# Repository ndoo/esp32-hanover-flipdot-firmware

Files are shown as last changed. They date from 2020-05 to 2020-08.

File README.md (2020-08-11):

# ESP32 Hanover Flip-dot Sign Controller

## PCB

Reference PCB is available at [ndoo/esp32-hanover-flipdot](https://github.com/ndoo/esp32-hanover-flipdot)

## Demo Video

[ESP32 Hanover Flip-dot Sign Controller - Demos](https://youtu.be/oSv1yEUelBg)

## Firmware

### IDE Prerequisites

You will need a working [VS Code](https://code.visualstudio.com/) and [PlatformIO](https://platformio.org/) development environment, with ESP32 support installed.

Libraries should automatically download as they have been specified in `platformio.ini`.

### First Use

#### Powering the Board

A freshly assembled board will not have any sketch running on it, and will be in bootloader bode waiting for firmware upload over serial. You will need a TTL USB-serial adapter, and one of the following methods of powering the board:

* Connect Tx, Rx, VCC and GND to USB-serial adapter - **USB-serial adapter must be set to 3.3V VCC or the ESP32 SIP will be irreversibly damaged**
* Connect Tx, Rx and GND to USB-serial adapter, then connect 18VDC power supply - **ground PCB to USB-serial adapter before connecting DC supply to avoid ESD**

**Do not connect RS-232 level signalling to the board, the ESP32 SIP will be damaged by signalling above TTL levels.**

#### Compiling and Uploading Sketch

The default `platformio.ini` provided here is configured to OTA upload for your convenience, however that means you need to edit this file for the initial flash, in order to program over USB-serial, as the board is not running firmware capable of OTA updates.

Comment these 2 lines out by preceding them with a semicolon (`;`):

```
upload_protocol = espota
upload_port = Hanover-Flipdot.local
```

Then, test the build by clicking the tick in the lower left status bar of VS Code + PlatformIO.

If the build succeeds, click the rightwards-pointing arrow in the lower left status bar of VS Code + PlatformIO. This will link the firmware and attempt to upload it to the board's ESP32 over USB-serial.

#### Configuring Wi-Fi

You should see a new wireless AP with the SSID `ESP_<YOUR_ESP_UNIQUE_MAC>`. Connect to it and you should be automatically redirected to a portal that allows you to connect the ESP32 to your Wi-Fi.

If the connection is successful, you should be able to send data to the board using the Python scripts found in the `demos` folder. If the connection fails, the ESP32 will automatically time out and re-start the temporary wireless AP for you to continue Wi-Fi setup.

Don't forget to uncomment the previously commented-out lines in `platformio.ini` to re-enable OTA uploads.

#### Rescue Programming

If you need to re-upload a sketch over serial, take note that this board does not have automatic boot and reset circuitry, so you will need to press the two buttons on the board in the following sequence to enter download mode, before uploading a sketch:

1. Hold down RST button
2. Hold down PGM button
3. Release RST button
4. Release PGM button

This may take a few tries to get the timing right, as the buttons are tiny and placed close together.

#### Troubleshooting

* Board not receiving UDP packets
  * The board, by default, listends on multicast IP 239.1.2.3 on UDP port 8080 (port can be changed in `include/main.h`)
  * Your LAN routers, switches or Wi-Fi access points may be configured to drop multicast packets, or may need IGMP snooping to be enabled
* OTA not working on Windows due to Hanover-Flipdot.local not resolving
  * You may need to install an mDNS resolver software such as [Apple's Bonjour Print Services for Windows](https://support.apple.com/kb/DL999)

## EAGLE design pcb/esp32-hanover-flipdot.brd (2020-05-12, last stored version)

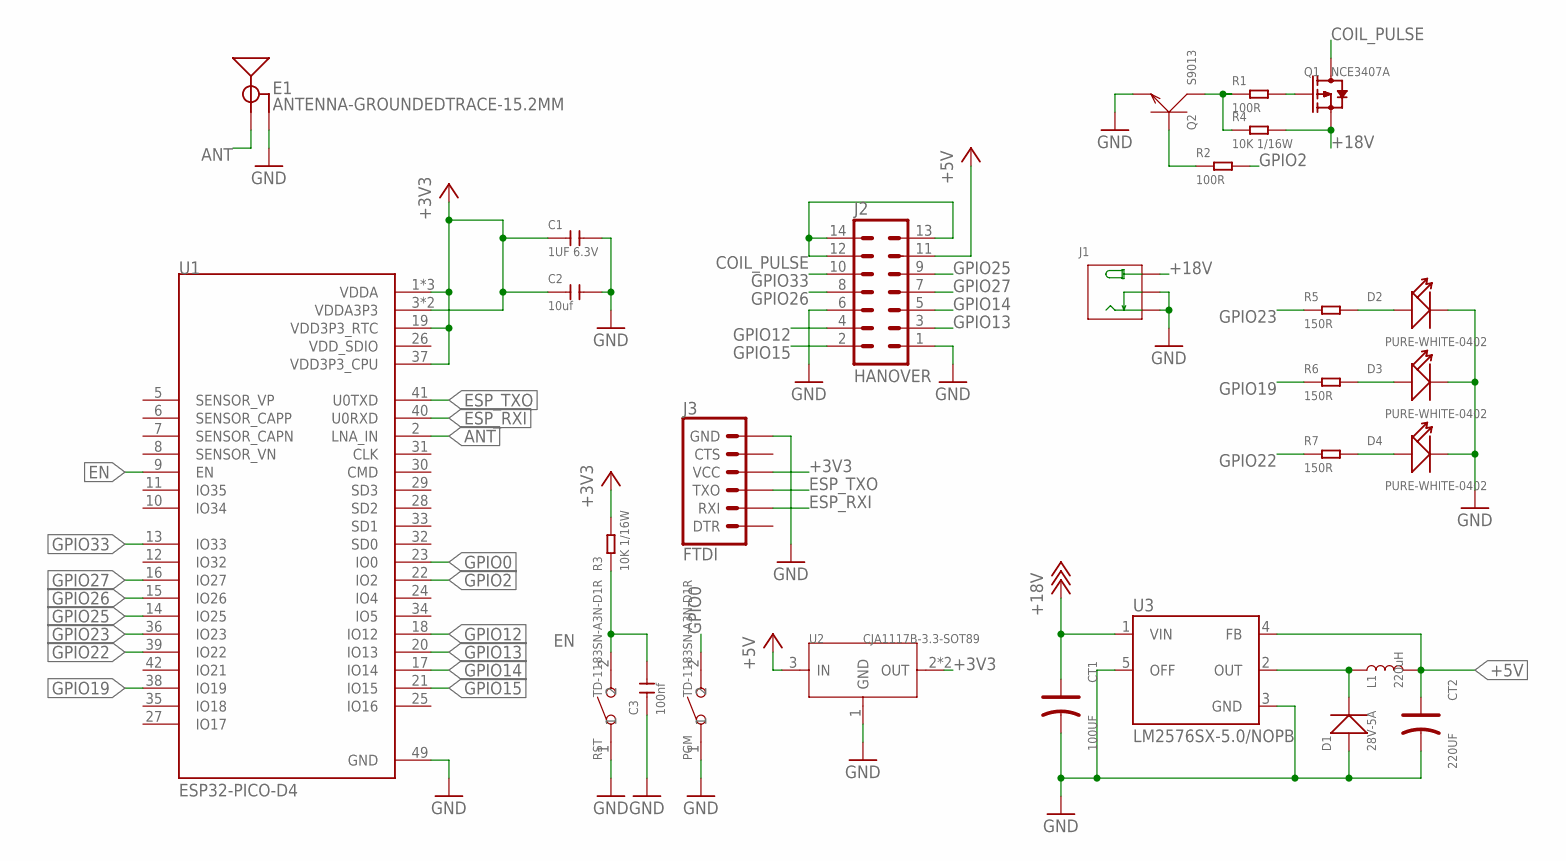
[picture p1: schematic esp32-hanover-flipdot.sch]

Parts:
C1: 1UF 6.3V; C0402
C2: 10uf; C0402
C3: 100nf; C0402
CT1: 100UF; ELECTRO-SMD-C-6MM; MPN 302030000
CT2: 220UF; ELECTRO-SMD-C-6MM
D1: 28V-5A; DO-214AA
D2, D3, D4: PURE-WHITE-0402; LED-0402
E1: ANTENNA-GROUNDEDTRACE-15.2MM; TRACE_ANTENNA_2.4GHZ_15.2MM
J1: DC-005; 3P-L14.2*W11.0*H9.0MM
J2: HANOVER; ML14
J3: FTDI; 6_PIN_SERIAL_TARGET_SIDE_W_SILK
L1: 220uH; CR54
PGM: TD-1183SN-A3N-D1R; SW2-2.6-3.0X2.5X1.2+0.4MM
Q1: NCE3407A; SOT-23
Q2: S9013; SOT-23
R1, R2: 100R; R0402
R3, R4: 10K 1/16W; R0402
R5, R6, R7: 150R; R0402; MPN RC0402FR-07150RL
RST: TD-1183SN-A3N-D1R; SW2-2.6-3.0X2.5X1.2+0.4MM
U1: ESP32-PICO-D4; PQFN50P700X700X104-49N
U2: CJA1117B-3.3-SOT89; SOT-89
U3: LM2576SX-5.0/NOPB; TO263-5

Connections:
+3V3: C1.1, C2.1, J3.P$4 (VCC), R3.2, U1.1 (VDDA), U1.3 (VDDA3P3), U1.4 (VDDA3P3), U1.19 (VDD3P3_RTC), U1.37 (VDD3P3_CPU), U1.43 (VDDA), U1.46 (VDDA), U2.2 (OUT), U2.4 (OUT)
+5V: CT2.+, J2.11, L1.P$2 (2), U2.3 (IN), U3.4 (FB)
+18V: CT1.+, J1.+B (+), J1.+T (+), Q1.2 (S), R4.2, U3.1 (VIN)
ANT: E1.ANT (SIGNAL), U1.2 (LNA_IN)
COIL_PULSE: J2.12, J2.13, J2.14, Q1.3 (D)
EN: C3.2, R3.1, RST.2, U1.9 (EN)
ESP_RXI: J3.P$3 (RXI), U1.40 (U0RXD)
ESP_TXO: J3.P$2 (TXO), U1.41 (U0TXD)
GND: C1.2, C2.2, C3.1, CT1.-, CT2.-, D1.+, D2.-, D3.-, D4.-, E1.GND, J1.-1B (-), J1.-1T (-), J1.-2B (CDN), J1.-2T (CDN), J2.1, J2.6, J3.P$6 (GND), PGM.1, Q2.2 (E), RST.1, U1.49 (GND), U2.1 (GND), U3.3 (GND), U3.5 (OFF)
GPIO0: PGM.2, U1.23 (IO0)
GPIO2: R2.2, U1.22 (IO2)
GPIO12: J2.4, U1.18 (IO12)
GPIO13: J2.3, U1.20 (IO13)
GPIO14: J2.5, U1.17 (IO14)
GPIO15: J2.2, U1.21 (IO15)
GPIO19: R6.1, U1.38 (IO19)
GPIO22: R7.1, U1.39 (IO22)
GPIO23: R5.1, U1.36 (IO23)
GPIO25: J2.9, U1.14 (IO25)
GPIO26: J2.8, U1.15 (IO26)
GPIO27: J2.7, U1.16 (IO27)
GPIO33: J2.10, U1.13 (IO33)
unnamed: Q1.1 (G), R1.2
unnamed: Q2.3 (C), R1.1, R4.1
unnamed: Q2.1 (B), R2.1
unnamed: D1.-, L1.P$1 (1), U3.2 (OUT)
unnamed: D2.+, R5.2
unnamed: D3.+, R6.2
unnamed: D4.+, R7.2
VDD_SDIO: U1.26 (VDD_SDIO)

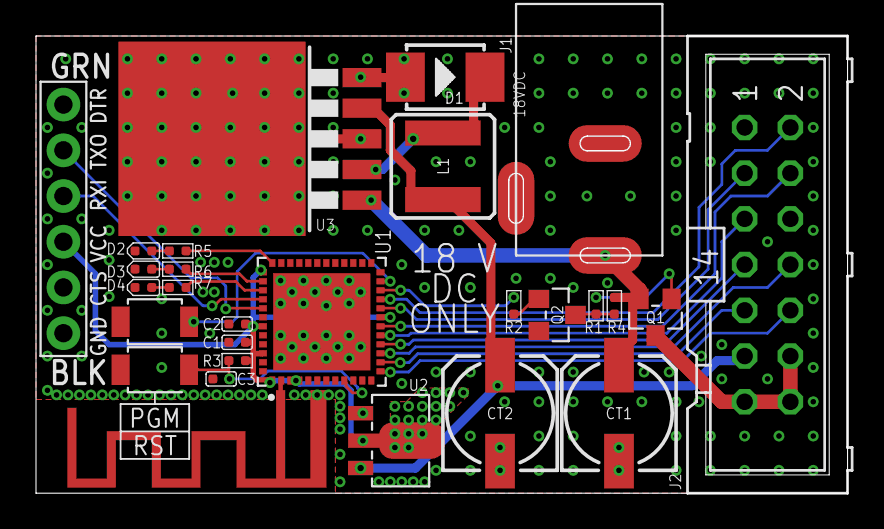
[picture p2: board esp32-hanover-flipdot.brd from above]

Board: 2 copper layers, 45.1 x 25.4 mm, 28 parts (0 on the bottom side), 29 nets.

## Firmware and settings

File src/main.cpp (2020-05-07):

#include <main.h>

#include <Arduino.h>
#include <WiFi.h>
#include <WiFiManager.h>
#include <ESPmDNS.h>
#include <WiFiUdp.h>
#include <ArduinoOTA.h>

extern "C"
{
#include "freertos/FreeRTOS.h"
}

#include <Hanover_Flipdot.h>
#include <Adafruit_GFX.h>
#include <Fonts/TomThumb.h>

#include "AsyncUDP.h"

Hanover_Flipdot flipdot = Hanover_Flipdot();
AsyncUDP udp;
IPAddress multicastGroup = IPAddress(239, 1, 2, 3);

bool panelOverride = false;

void debugText(String text, uint8_t seconds = 0)
{
    if (seconds)
        flipdot.backup();
    flipdot.clear();
    flipdot.setCursor(0, 5);
    flipdot.print(text);
    flipdot.writeDisplay();
    if (seconds)
    {
        sleep(seconds);
        flipdot.restore();
        flipdot.writeDisplay();
    }
}

void configModeCallback(WiFiManager *myWiFiManager)
{
    debugText("Setup: " + myWiFiManager->getConfigPortalSSID());
}

void onUdpPacket(AsyncUDPPacket packet)
{
    if (panelOverride)
        return;

    uint16_t len = (uint16_t)flipdot.getWidth() * flipdot.getHeight() / 8;
    if (packet.length() != len)
        return;

    memcpy(flipdot.db_buffer, packet.data(), len);
    flipdot.writeDisplay();
}

void connectToUdp()
{
    if (udp.listenMulticast(multicastGroup, UDP_PORT))
    {
        // Power optimizations
        setCpuFrequencyMhz(80);

        // Uncomment for better receive performance, e.g. for videos
        // ESP32 may get hot!
        WiFi.setSleep(false);

        // UDP handler function
        udp.onPacket(onUdpPacket);
    }
}

void WiFiEvent(WiFiEvent_t event)
{
    Serial.printf("[WiFi-event] event: %d\n", event);
    String ip_msg = "IP: ";
    ip_msg += multicastGroup.toString() + "\nPort: " + UDP_PORT;
    switch (event)
    {
    case SYSTEM_EVENT_STA_START:
        debugText("Wi-Fi connecting", 3);
        break;
    case SYSTEM_EVENT_STA_GOT_IP:
        connectToUdp();
        debugText(ip_msg);
        break;
    case SYSTEM_EVENT_STA_DISCONNECTED:
        debugText("Wi-Fi lost", 3);
        break;
    case SYSTEM_EVENT_STA_LOST_IP:
        debugText("Wi-Fi lost IP", 3);
        break;
    }
}
void setup()
{

    Serial.begin(115200);

    flipdot.begin();
    flipdot.setFont(&TomThumb);
    flipdot.setTextSize(1);

    WiFi.onEvent(WiFiEvent);

    WiFiManager wifiManager;
    wifiManager.setAPCallback(configModeCallback);
    wifiManager.setHostname("Hanover-Flipdot");
    wifiManager.autoConnect();

    ArduinoOTA.onStart([]() {
                  // Stash flipdot contents and lock display to prevent slowdown of OTA by synchronous display updates from UDP
                  flipdot.backup();
                  panelOverride = true;
                  String type;
                  if (ArduinoOTA.getCommand() == U_FLASH)
                  {
                      type = "FW";
                  }
                  else
                  { // U_FS
                      type = "FS";
                  }
                  debugText("OTA " + type);
              })
        .onProgress([](unsigned int progress, unsigned int total) {
            String ota_msg = "OTA ";
            ota_msg += String(progress / (total / 100)) + "%";
            debugText(ota_msg);
        })
        .onEnd([]() {
            debugText("OTA success!");
        })
        .onError([](ota_error_t error) {
            String ota_msg = "OTA error " + String(error) + ":\n";
            switch (error)
            {
            case OTA_AUTH_ERROR:
                ota_msg += "Auth Failed";
                break;
            case OTA_BEGIN_ERROR:
                ota_msg += "Begin Failed";
                break;
            case OTA_CONNECT_ERROR:
                ota_msg += "Connect Failed";
                break;
            case OTA_RECEIVE_ERROR:
                ota_msg += "Receive Failed";
                break;
            case OTA_END_ERROR:
                ota_msg += "End Failed";
                break;
            }
            debugText(ota_msg);
            sleep(3);
            panelOverride = false;
            flipdot.restore();
            flipdot.writeDisplay();
        });

    ArduinoOTA.begin();
}

void loop()
{
    ArduinoOTA.handle();
}

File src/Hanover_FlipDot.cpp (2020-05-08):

#include <Hanover_Flipdot.h>
#include <Arduino.h>
#include <Adafruit_GFX.h>
#include <SPI.h>
#include <Wire.h>
#include <rom/rtc.h>

static const uint8_t pin_enable[] = {PIN_ENABLE1, PIN_ENABLE2, PIN_ENABLE3, PIN_ENABLE4};

Hanover_Flipdot::Hanover_Flipdot(void) : Adafruit_GFX(DB_COLS * DB_BOARDS, DB_ROWS)
{
}

void Hanover_Flipdot::begin(void)
{

    // Set GPIO pins of dot board to output
    pinMode(PIN_ENABLE1, OUTPUT);
    pinMode(PIN_ENABLE2, OUTPUT);
    pinMode(PIN_ENABLE3, OUTPUT);
    pinMode(PIN_ENABLE4, OUTPUT);
    pinMode(PIN_ROW_ADVANCE, OUTPUT);
    pinMode(PIN_COL_ADVANCE_ROW_RESET, OUTPUT);
    pinMode(PIN_COL_RESET, OUTPUT);
    pinMode(PIN_SET_UNSET, OUTPUT);
    pinMode(PIN_COIL_DRIVE, OUTPUT);

    // Set GPIO pins of status LEDs to output
    pinMode(PIN_LED_COIL, OUTPUT);
    pinMode(PIN_LED_ROW, OUTPUT);
    pinMode(PIN_LED_COL, OUTPUT);

    // Set GPIO pins of dot board to low (to avoid potentially overheating coils)
    digitalWrite(PIN_ENABLE1, LOW);
    digitalWrite(PIN_ENABLE2, LOW);
    digitalWrite(PIN_ENABLE3, LOW);
    digitalWrite(PIN_ENABLE4, LOW);
    digitalWrite(PIN_ROW_ADVANCE, LOW);
    digitalWrite(PIN_COL_ADVANCE_ROW_RESET, LOW);
    digitalWrite(PIN_COL_RESET, LOW);
    digitalWrite(PIN_SET_UNSET, LOW);
    digitalWrite(PIN_COIL_DRIVE, LOW);

    if (rtc_get_reset_reason(0) == 1 || rtc_get_reset_reason(0) == 15)
    { // POWERON_RESET || RTCWDT_BROWN_OUT_RESET
        // Lamp test while waiting for power to stabilize (if cold boot)
        digitalWrite(PIN_LED_COIL, HIGH);
        digitalWrite(PIN_LED_ROW, HIGH);
        digitalWrite(PIN_LED_COL, HIGH);
        sleep(1);
    }

    // Set GPIO pins of status LEDs
    digitalWrite(PIN_LED_COIL, LOW);
    digitalWrite(PIN_LED_ROW, LOW);
    digitalWrite(PIN_LED_COL, LOW);

    // Lamp test / force clear
    fillScreen(1);
    writeDisplay();
    clear();
    writeDisplay();
}

uint8_t Hanover_Flipdot::getWidth(void)
{
    return DB_COLS * DB_BOARDS;
}
uint8_t Hanover_Flipdot::getHeight(void)
{
    return DB_ROWS;
}

void Hanover_Flipdot::enable(uint8_t db)
{
    // Unlatch dot board
    digitalWrite(pin_enable[db], HIGH);

    // Clear row and column resets
    digitalWrite(PIN_COL_ADVANCE_ROW_RESET, LOW);
    digitalWrite(PIN_COL_RESET, LOW); // Clear column reset after row, as row reset advances column
}

void Hanover_Flipdot::disable(uint8_t db)
{
    // Hold row and column counters in reset
    digitalWrite(PIN_COL_ADVANCE_ROW_RESET, HIGH);
    digitalWrite(PIN_COL_RESET, HIGH); // Set column reset after row, as row reset advances column

    // Latch dot board
    digitalWrite(pin_enable[db], LOW);
}

void Hanover_Flipdot::advanceRow(void)
{
    digitalWrite(PIN_ROW_ADVANCE, HIGH);
    if (LED_DEBUG)
        digitalWrite(PIN_LED_ROW, HIGH);
    delayMicroseconds(1);
    digitalWrite(PIN_ROW_ADVANCE, LOW);
    if (LED_DEBUG)
        digitalWrite(PIN_LED_ROW, LOW);
    delayMicroseconds(1);
}

void Hanover_Flipdot::advanceCol(void)
{
    digitalWrite(PIN_COL_ADVANCE_ROW_RESET, HIGH);
    if (LED_DEBUG)
        digitalWrite(PIN_LED_COL, HIGH);
    delayMicroseconds(1);
    digitalWrite(PIN_COL_ADVANCE_ROW_RESET, LOW);
    if (LED_DEBUG)
        digitalWrite(PIN_LED_COL, LOW);
    delayMicroseconds(1);
}

void Hanover_Flipdot::flipDot(bool state, uint16_t pulse_time)
{
    digitalWrite(PIN_SET_UNSET, state ^ DB_INVERT ? HIGH : LOW);
    digitalWrite(PIN_COIL_DRIVE, HIGH);
    if (LED_DEBUG)
        digitalWrite(PIN_LED_COIL, HIGH);

    delayMicroseconds(pulse_time);

    digitalWrite(PIN_COIL_DRIVE, LOW);
    if (LED_DEBUG)
        digitalWrite(PIN_LED_COIL, LOW);

    delayMicroseconds(DB_THROTTLE);
}
void Hanover_Flipdot::writeDisplay(void)
{
    // Iterate dot boards
    for (uint8_t db = 0; db < DB_BOARDS; db++)
    {
        bool db_enabled = false;

        uint8_t col_start = db * DB_COLS;
        uint8_t col_end = col_start + DB_COLS;

        // Iterate columns
        uint8_t col_backlog = 0;
        for (uint8_t col = col_start; col < col_end; col++)
        {
            // Iterate rows
            uint8_t row_backlog = 0;
            for (uint8_t row = 0; row < DB_ROWS; row++)
            {
                bool db_buffer_bit = db_buffer[col] & (1 << row);
                bool db_displayed_bit = db_displayed[col] & (1 << row);
                if (db_displayed_bit != db_buffer_bit)
                {
                    // Enable dot-board if first time writing
                    if (!db_enabled)
                    {
                        enable(db);
                        db_enabled = true;
                    }

                    // Increment to match
                    for (uint8_t cb = 0; cb < col_backlog; cb++)
                        advanceCol();
                    for (uint8_t rb = 0; rb < row_backlog; rb++)
                        advanceRow();
                    row_backlog = 0;
                    col_backlog = 0;

                    uint16_t pulse_time = pow(db, 2) * DB_SEQ_THROTTLE_COIL + (db_buffer_bit ? PULSE_COIL_ON : PULSE_COIL_OFF);
                    flipDot(db_buffer_bit, pulse_time);
                }
                row_backlog++;
            } // Iterate rows
            db_displayed[col] = db_buffer[col];
            Serial.println();
            col_backlog++;
        } // Iterate columns
        if (db_enabled)
            disable(db);
    } // Iterate dot boards
}

// Drawing helper functions

void Hanover_Flipdot::clear(void)
{
    for (uint8_t i = 0; i < DB_COLS * DB_BOARDS; i++)
        db_buffer[i] = 0;
}

void Hanover_Flipdot::backup(void)
{
    memcpy(db_backup, db_buffer, sizeof(db_buffer));
}

void Hanover_Flipdot::restore(void)
{
    memcpy(db_buffer, db_backup, sizeof(db_backup));
}

// Drawing functions (Adafruit GFX Primitives)

void Hanover_Flipdot::drawPixel(int16_t x, int16_t y, uint16_t color)
{
    if ((y < 0) || (y >= DB_ROWS))
        return;
    if ((x < 0) || (x >= DB_COLS * DB_BOARDS))
        return;

    if (color)
    {
        db_buffer[x] |= 1 << y;
    }
    else
    {
        db_buffer[x] &= ~(1 << y);
    }
}

void Hanover_Flipdot::fillScreen(uint16_t color)
{
    for (uint8_t i = 0; i < DB_COLS * DB_BOARDS; i++)
        db_buffer[i] = pow(2, DB_ROWS) - 1;
}

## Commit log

2018-11-21 Changed more tName silkscreen text to 11% ratio, fixed R2 silkscreen overlap with CT2 pad, update PCB image.
    [esp32-hanover-flipdot.brd]
2020-05-04 Add PlatformIO project for code that drives the board
    Add PlatformIO project for code that drives the board. Documentation TODO.
2020-05-04 Fix reset routines and transmit data over binary UDP
    [Hanover_FlipDot.cpp, Hanover_Flipdot.h, main.cpp]
2020-05-05 PCB: Disconnect dot board pin 13, 14. Add 18VDC and warning text. Increase space around J2.
    Disconnect dot-board pin 13 and 14 from 18VDC, seems to cause overheating of dot 0,0 on dot boards when boards are not enabled. Works fine without anyway - tested by cutting ribbon cable pins 13, 14.
    Added 18VDC only warning text. Add warning text to disconnect power before connecting or disconnecting dot boards.
    Increase space around J2 as the connector housing is causing stress to neighboring components.
    [esp32-hanover-flipdot.brd, esp32-hanover-flipdot.sch]
2020-05-05 Fix Eagle Seeedstudio DRC
    Routed missing airwires and approved clearance issues
    [esp32-hanover-flipdot.brd]
2020-05-05 Create esp32-hanover-flipdot_2020-05-05-seeed-fusion.zip
    Generate Seeed Fusion PCB Gerbers using Eagle's built in Seeed Fusion 2-layer template
2020-05-05 Update README.md
    Recommend buying 2.54mm through-holes locally to save time/money
2020-05-05 Fix warning silkscreen clipping outside of board dimension
    [esp32-hanover-flipdot.brd]
2020-05-06 More Demos and Updates to Demos
    New demos:
    * clock.py - A simple clock
    * fill.py - Dotboard test - cycles between all on and all off
    * webcam.py - Sends webcam feed to dotboard (written for Windows, trivial to adapt by changing the capture device to 0)
    Improvements/changes
    * imageToBinary.py - invert image as contrast tends to favor white on black on flipdots
    * All demos - change to 96*32 (3* 32*32 dot boards) as that's what I have on hand
2020-05-06 Firmware: Improve stability for 3+ dot boards
    Improvements for stability for 3 dot boards (and presumably the maximum supported, 4) by adding additional exponential delay for each dot board chained from the first.
    The main difference is that voltage droops due to the longer distance (resistance/capacitance) requires extra coil pulse time.
    Disable Wi-Fi sleep again, as heat output is manageable; I had faulty dot boards drawing heavily on the 5V rail causing the main switching regulator to generate excessive heat, but it turns out the ESP32 does not get too hot even with Wi-Fi sleep turned off.
    Disable display from UDP during OTA update to avoid blocking OTA thread.
    [Hanover_FlipDot.cpp, Hanover_Flipdot.h, main.cpp]
2020-05-06 PCB: Layout improvements and parts substitutions
    Board:
    * Increase ground plane stitching especially for heatsinking of regulators and ESP32
    * Add pour and stitching on +3V3 LDO regulator for heatsinking
    * Increase voltage trace sizes to conduct heat away from power components/decrease voltage droop
    Schematic:
    * Disconnect dot board pin 14 from 18V, it seems to cause erratic behavior on dot boards. Not sure what the function of this 18V supply pin is, but boards work fine with this line snipped off
    * Add dot board pin 13 to existing COIL_PULSE net on pin 14, as they are internally shorted on the dot boards - this should double the current capacity/halve the voltage droop on the cable to the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
    [bom.csv, esp32-hanover-flipdot.brd, esp32-hanover-flipdot.sch]
2020-05-06 PCB: Cleanup for Seeed Fusion
    Board and Schematic:
    * Change LM2576 part to match BOM
    Other documents:
    * Exported a new set of Gerbers and matching pick and place files and top of PCB drawing
    [esp32-hanover-flipdot.brd, esp32-hanover-flipdot.sch]
2020-05-07 Update Hanover_Flipdot.h
    Add support for older revision of PCB
2020-05-07 Update bom.csv
    J2 should be vertical header and not right angle
    [bom.csv]
2020-05-07 Hanover_Flipdot: Remove support for vertically stacked dot boards; Change buffer to 1D array of 32-bit columns
    Remove support for vertically stacked dot boards:
    Now dot boards can only be chained left to right, there is no support for vertically stacked dotboards e.g. 1x2, 2x2 dotboards. In any case, 2D dotboard matrixes was never really supported by the wri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
    Change buffer to 1D array of 32-bit columns:
    This is to make the buffer format much more similar to Hanover's RS-485 signalling, in preparating for future work to integrate Hanover RS-485 protocol support.
    Other functions had to be re-written to become bitwise operations to the buffer.
    UDP receive of video frames now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
2020-05-07 Demos: Add image.py
    Sends an image to the dot board. This inverts twice (i.e. it does not invert), so your image should be color on black for best contrast.
2020-05-07 Firmware: Improve error messages
    Error messages now backup previous contents, and restore the original contents.
    The most noticeable improvement is that Wi-Fi disconnects no longer cause board contents to be lost.
    [Hanover_FlipDot.cpp, Hanover_Flipdot.h, main.cpp]
2020-05-08 Demos: Clock visual changes, font filename case sensitive
    Clock visual layout changes
    Fix font file name for case sensitive filesystems.
2020-05-08 Firmware: Fix coil pulse uint8_t overflow, change enable/disable routine, LED pin naming changes, increase coil pulse times
    Fix coil pulse uint8_t overflow:
    flipDot() routine used uint8_t type for pulse_time, leading to an integer overflow that prevented further dot boards from flipping dots due to insufficient pulse_time. uint16_t data type fixes this (for now).
    Change enable/disable routine:
    A previous change to enable-only routine in commit 3168280bb8c06442f1713e7cbb857c4e17712baf causes dot board 4 to be left enabled after a writeDisplay(), it should be left disabled when not in use; re-implementing disable() functionality fixes this.
    LED pin naming changes for clarity.
    Increase coil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
    [Hanover_FlipDot.cpp, Hanover_Flipdot.h]
2020-05-12 pcb: Connect dot board pin 14 to COIL_PULSE (pin 12, pin 13) too
    The 18V supply on this pin doesn't seem to be used, as it's wired to column darlington arrays while the dot boards seem to use the row darlingtons to source/sink. In any case, it should be safe to connect, tested splicing pin 12+13+14 together on a real dot board and it worked fine.
    [esp32-hanover-flipdot.brd, esp32-hanover-flipdot.sch]
2020-05-12 pcb: Increase isolation and ground stitching around 18V pulse line
    [esp32-hanover-flipdot.sch]
2020-05-17 Clean up non-firmware files for fork to firmware-only repository
    [bom.csv, esp32-hanover-flipdot.brd, esp32-hanover-flipdot.sch]
2020-08-24 Add gameoflife demo and change some board sizes to 64*32 for testing

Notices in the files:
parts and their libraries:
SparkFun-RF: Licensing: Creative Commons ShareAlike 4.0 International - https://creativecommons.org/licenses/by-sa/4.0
